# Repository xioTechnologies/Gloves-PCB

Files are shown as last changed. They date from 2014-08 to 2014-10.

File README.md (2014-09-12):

Gloves-PCB
==========

Temporary PCB solution for [the gloves](http://theglovesproject.com/).  Design include five separate PCBs: one main board, two LED boards and two vibration motor boards.  The main board mounts an [x-OSC](http://www.x-io.co.uk/products/x-osc/) an [x-BIMU](http://www.x-io.co.uk/products/x-bimu/) and features an LED bar graph to indicate battery level using the [LM3914](https://www.sparkfun.com/products/12694).  More information available on [blog post](http://theglovesproject.com/breakout-board-for-nime/).

Images
------

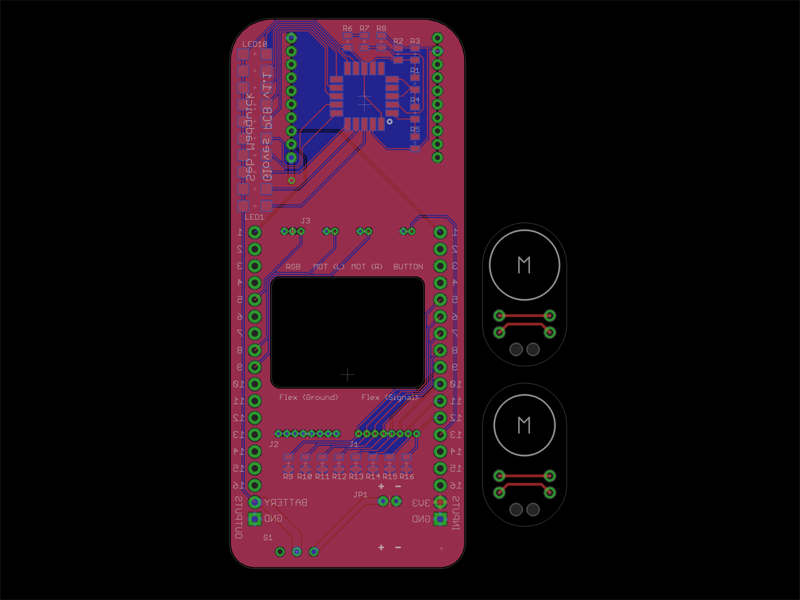
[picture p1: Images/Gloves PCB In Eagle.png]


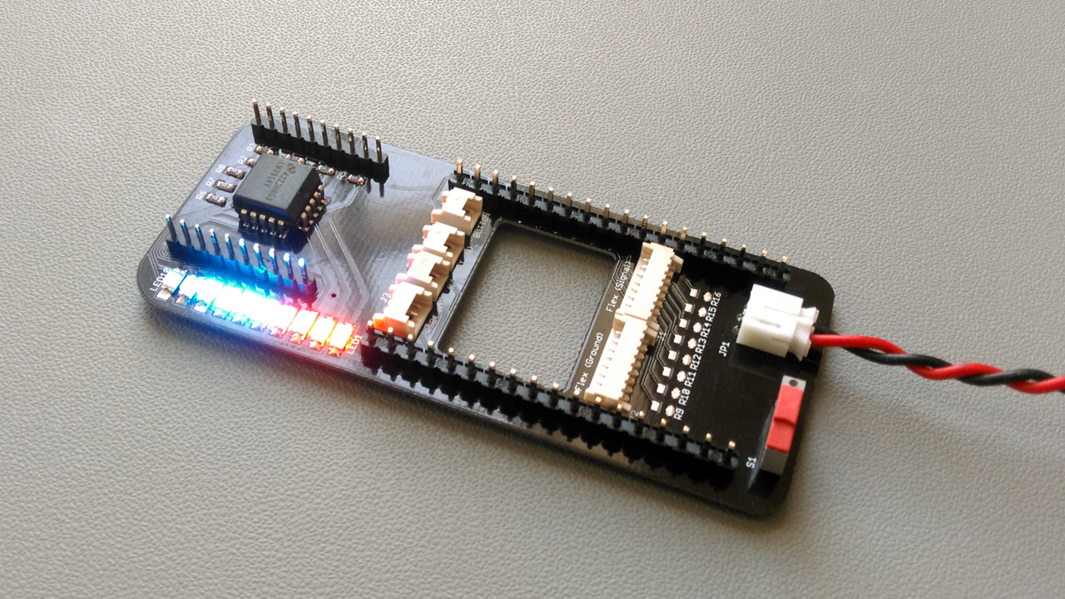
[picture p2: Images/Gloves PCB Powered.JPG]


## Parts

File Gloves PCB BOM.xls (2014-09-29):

ID | Qty | Part | Description
J1, J2 | 2 | Farnell: 973-3094 (http://uk.farnell.com/molex/53048-0810/header-right-angle-8way/dp/9733094?Ntt=973-3094) | 8-way Molex PicoBlade
J3 | 1 | Farnell: 973-2918 (http://uk.farnell.com/molex/53048-0310/connector-header-tht-ra-1-25mm/dp/9732918?Ntt=973-2918) | 3-way Molex PicoBlade
J4, J5, J6 | 3 | Farnell: 101-2259 (http://uk.farnell.com/molex/53048-0210/connector-header-tht-ra-1-25mm/dp/1012259?Ntt=101-2259) | 2-way Molex PicoBlade
JP1 | 1 | RS: S2B-PH-K-S(LF)(SN) (http://uk.rs-online.com/web/p/pcb-headers/5468962/) | JST socket
S1 | 1 | RS: 785-6469 (http://uk.rs-online.com/web/p/products/7856469/) | Slide switch
R1, R4, R5, R6, R7, R8 | 6 | 10k, 603 | Resistor
R2,R3 | 2 | 1k5, 0603 | Resistor
U1 | 1 | RS:534-2983 (http://uk.rs-online.com/web/p/products/5342983/) | LM3914 LED driver
LED1, LED2, LED3, LED4 | 4 | RS: 692-0862 (http://uk.rs-online.com/web/p/products/6920862/) | Orange LED
LED5, LED6, LED7, LED8, LED9, LED10 | 6 | RS: 692-0887 (http://uk.rs-online.com/web/p/products/6920887/) | Blue LED
R9, R10, R11, R12, R13, R14, R15, R16 | 8 | 26k1, 0603 | Resistor
x-BIMU-TH | 2 | Sparkfun: PRT-10112 (https://www.sparkfun.com/products/10112) | 2mm pitch header
x-OSC-TH | 2 | LHCS-18S-R-027-034 (http://www.toby.co.uk/content/catalogue/products.aspx?series=LHCS-xxS-R-027-xxx) | 2.54mm pitch header

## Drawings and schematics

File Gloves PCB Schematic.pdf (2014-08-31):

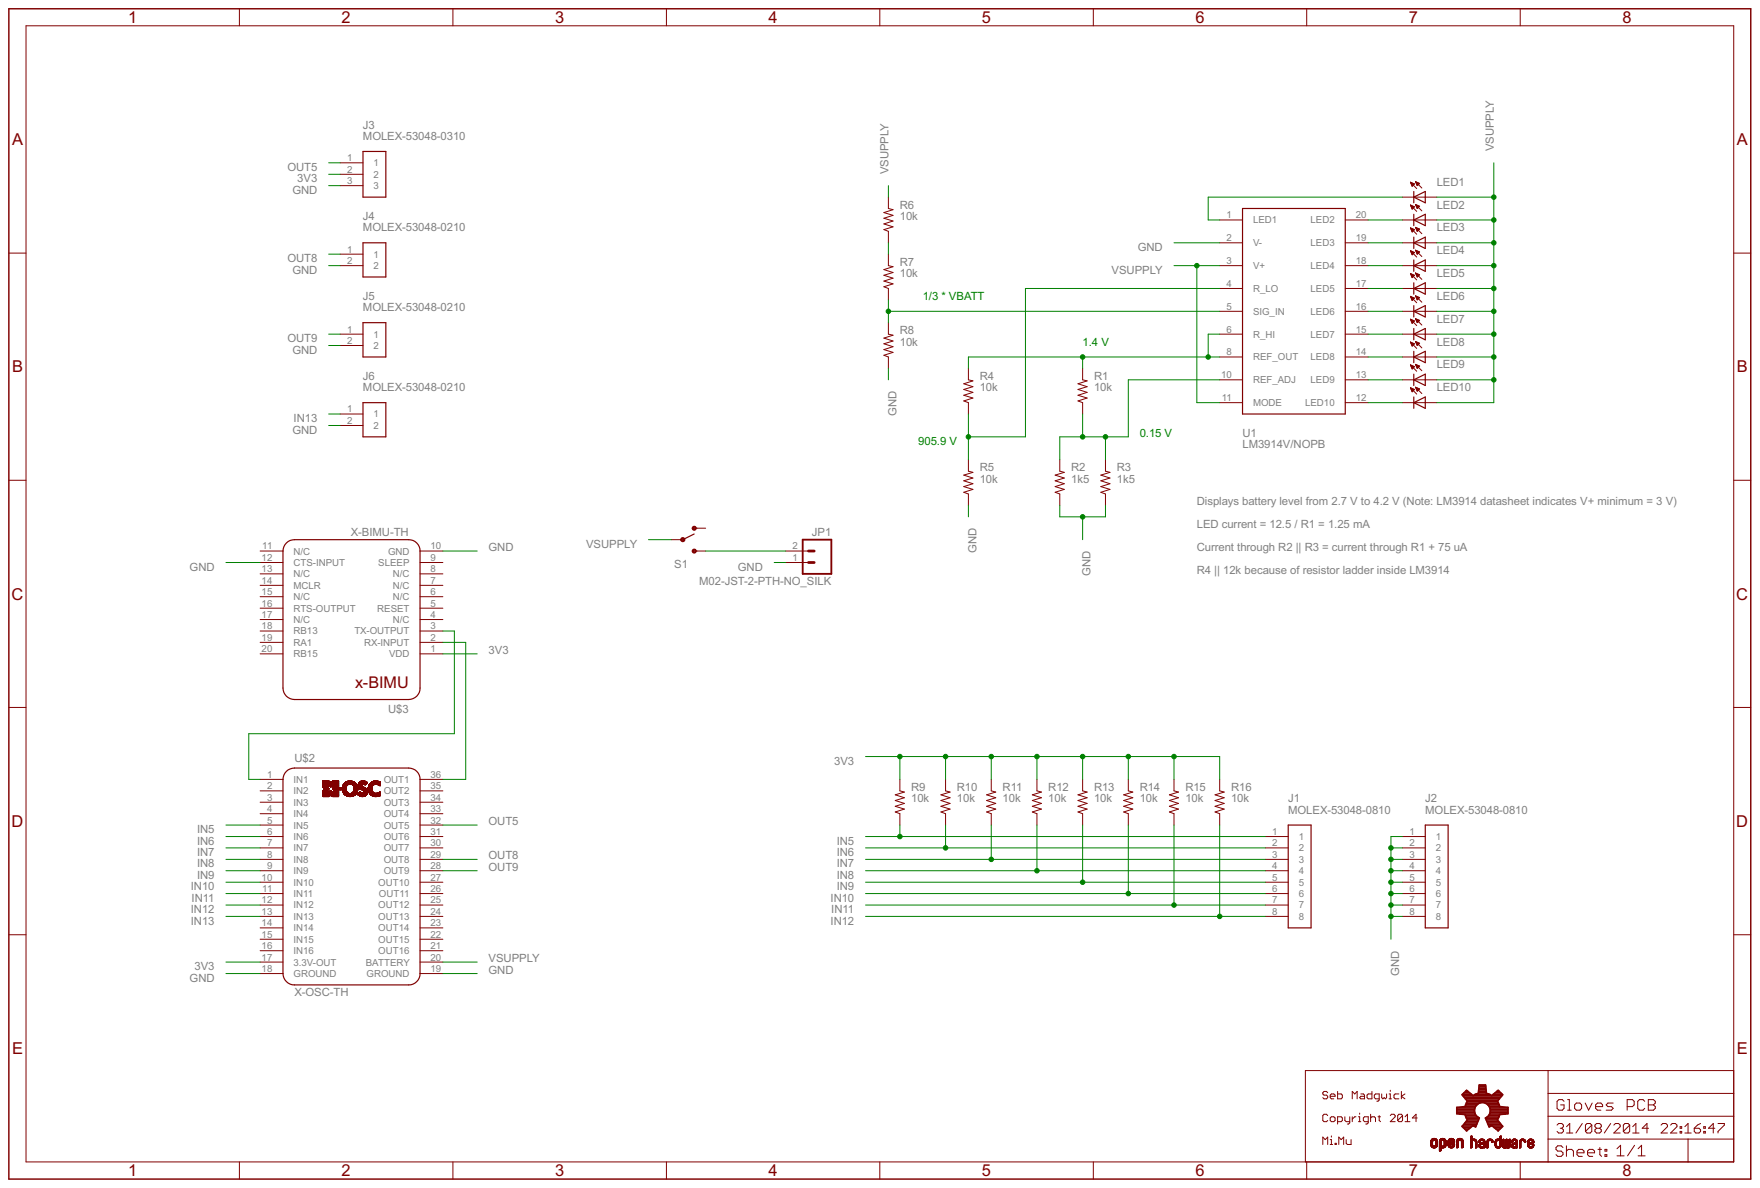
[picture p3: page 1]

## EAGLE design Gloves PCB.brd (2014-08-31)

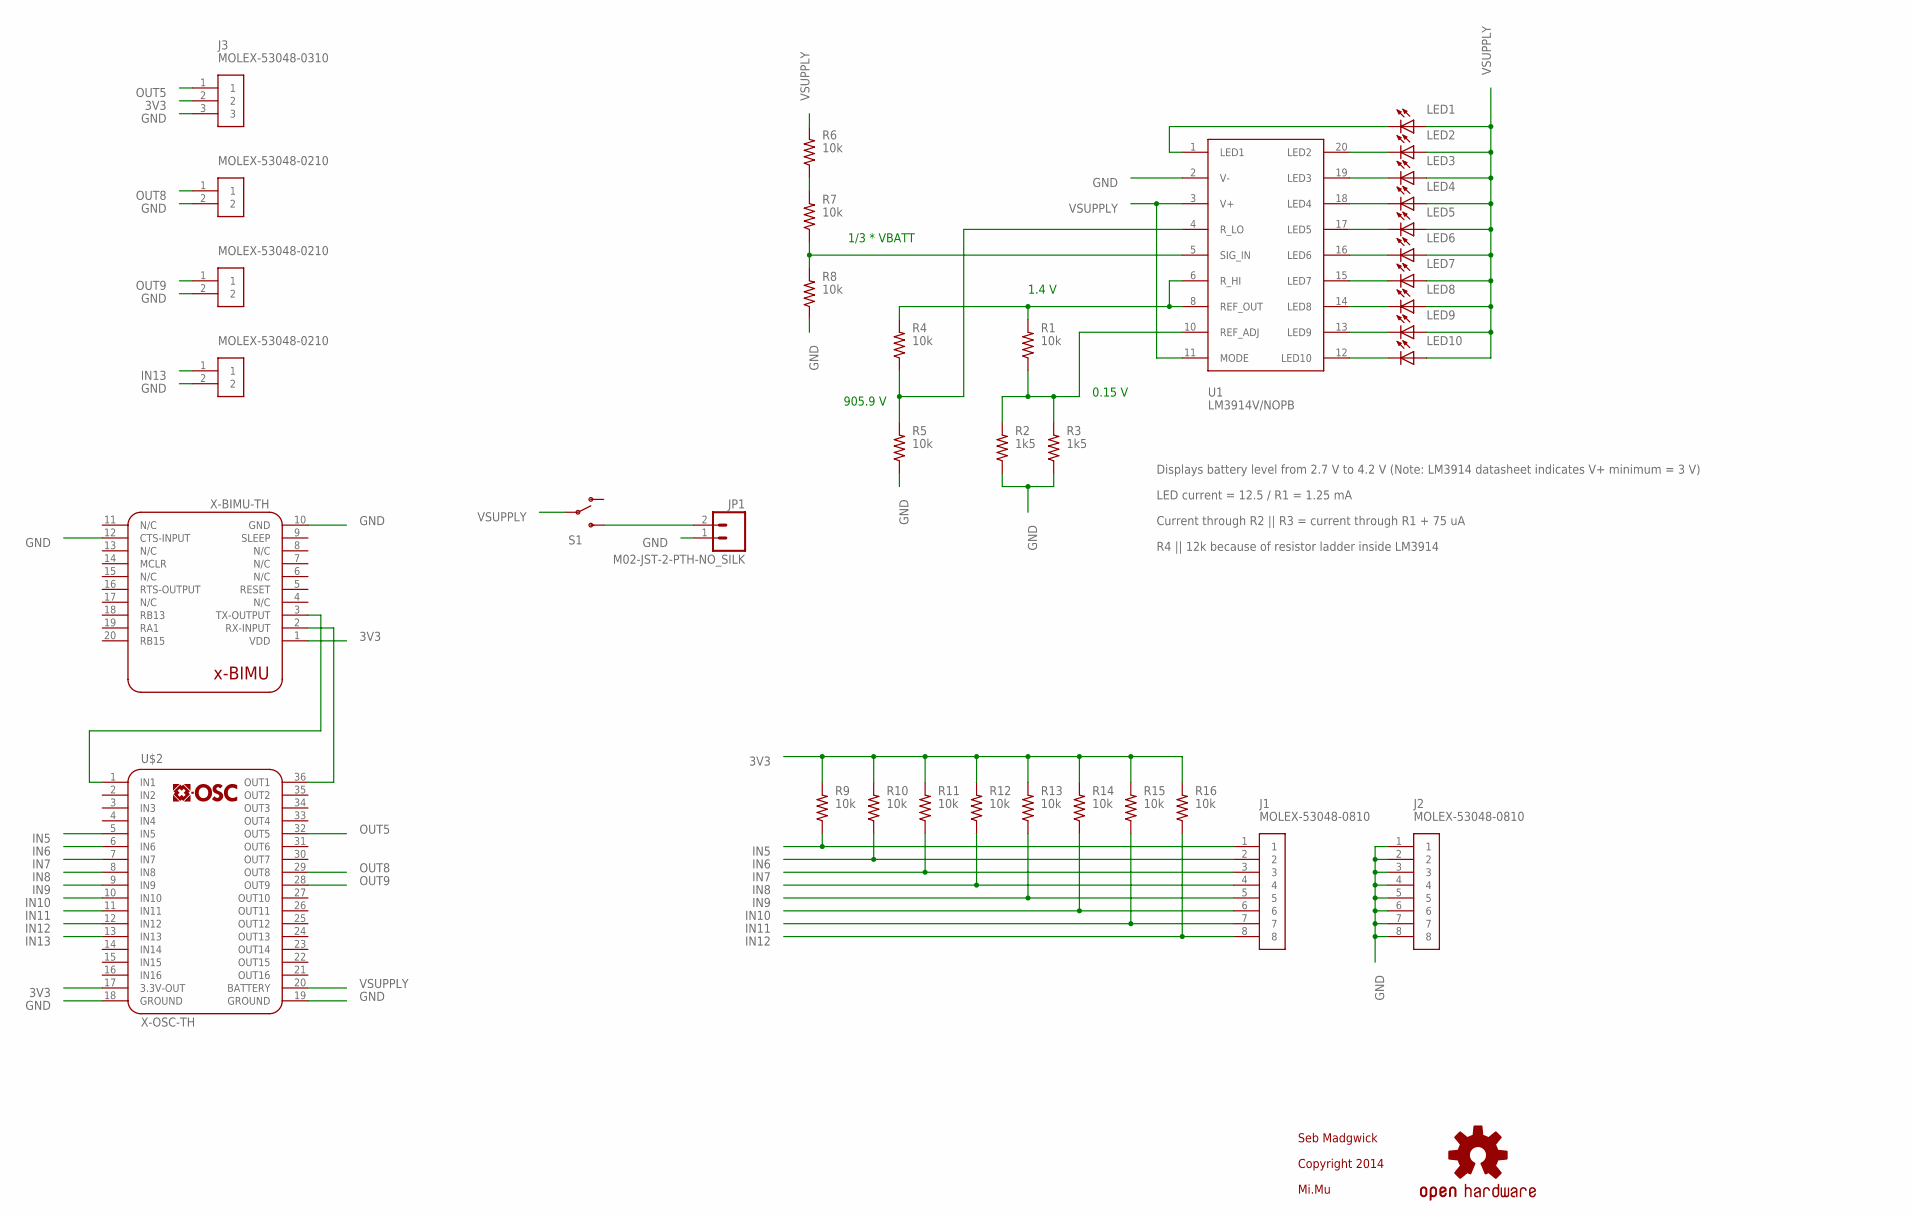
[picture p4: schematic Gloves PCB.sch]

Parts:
J1, J2: MOLEX-53048-0810
J3: MOLEX-53048-0310
J4, J5, J6: MOLEX-53048-0210
JP1: M02-JST-2-PTH-NO_SILK; JST-2-PTH-NS
LED1, LED2, LED3, LED4, LED5, LED6, LED7, LED8, LED9, LED10: LEDCHIPLED_1206; CHIPLED_1206
R1, R4, R5, R6, R7, R8, R9, R10, R11, R12, R13, R14, R15, R16: 10k; 0805
R2, R3: 1k5; 0805
S1: SWITCH-DPST; WURTH-ELEKTRONIK-450301014042
U1: LM3914V/NOPB; PLCC-20
U$1: OSHW-LOGOS; OSHW-LOGO-S
U$2: X-OSC-TH; X-OSC_TH
U$3: X-BIMU-TH; X-BIMU_TH

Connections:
3V3: J3.2, R9.2, R10.2, R11.2, R12.2, R13.2, R14.2, R15.2, R16.2, U$2.17 (3.3V-OUT), U$3.1 (VDD)
GND: J2.1, J2.2, J2.3, J2.4, J2.5, J2.6, J2.7, J2.8, J3.3, J4.2, J5.2, J6.2, JP1.1, R2.1, R3.1, R5.1, R8.1, U1.2 (V-), U$2.18 (GROUND), U$2.19 (GROUND), U$3.10 (GND), U$3.12 (CTS-INPUT)
IN5: J1.1, R9.1, U$2.5 (IN5)
IN6: J1.2, R10.1, U$2.6 (IN6)
IN7: J1.3, R11.1, U$2.7 (IN7)
IN8: J1.4, R12.1, U$2.8 (IN8)
IN9: J1.5, R13.1, U$2.9 (IN9)
IN10: J1.6, R14.1, U$2.10 (IN10)
IN11: J1.7, R15.1, U$2.11 (IN11)
IN12: J1.8, R16.1, U$2.12 (IN12)
IN13: J6.1, U$2.13 (IN13)
unnamed: U$2.1 (IN1), U$3.3 (TX-OUTPUT)
unnamed: R4.1, R5.2, U1.4 (R_LO)
unnamed: JP1.2, S1.3
unnamed: R7.1, R8.2, U1.5 (SIG_IN)
unnamed: R6.1, R7.2
unnamed: R1.1, R2.2, R3.2, U1.10 (REF_ADJ)
unnamed: LED10.C, U1.12 (LED10)
unnamed: LED9.C, U1.13 (LED9)
unnamed: LED8.C, U1.14 (LED8)
unnamed: LED7.C, U1.15 (LED7)
unnamed: LED6.C, U1.16 (LED6)
unnamed: LED5.C, U1.17 (LED5)
unnamed: LED4.C, U1.18 (LED4)
unnamed: LED3.C, U1.19 (LED3)
unnamed: LED2.C, U1.20 (LED2)
unnamed: LED1.C, U1.1 (LED1)
unnamed: U$2.36 (OUT1), U$3.2 (RX-INPUT)
OUT5: J3.1, U$2.32 (OUT5)
OUT8: J4.1, U$2.29 (OUT8)
OUT9: J5.1, U$2.28 (OUT9)
REF_OUT: R1.2, R4.2, U1.6 (R_HI), U1.8 (REF_OUT)
VSUPPLY: LED1.A, LED2.A, LED3.A, LED4.A, LED5.A, LED6.A, LED7.A, LED8.A, LED9.A, LED10.A, R6.2, S1.2, U1.3 (V+), U1.11 (MODE), U$2.20 (BATTERY)

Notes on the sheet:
Seb Madgwick
1.4 V
0.15 V
905.9 V
Displays battery level from 2.7 V to 4.2 V (Note: LM3914 datasheet indicates V+ minimum = 3 V)
1/3 * VBATT
LED current = 12.5 / R1 = 1.25 mA
Current through R2 || R3 = current through R1 + 75 uA
R4 || 12k because of resistor ladder inside LM3914
Copyright 2014
Mi.Mu

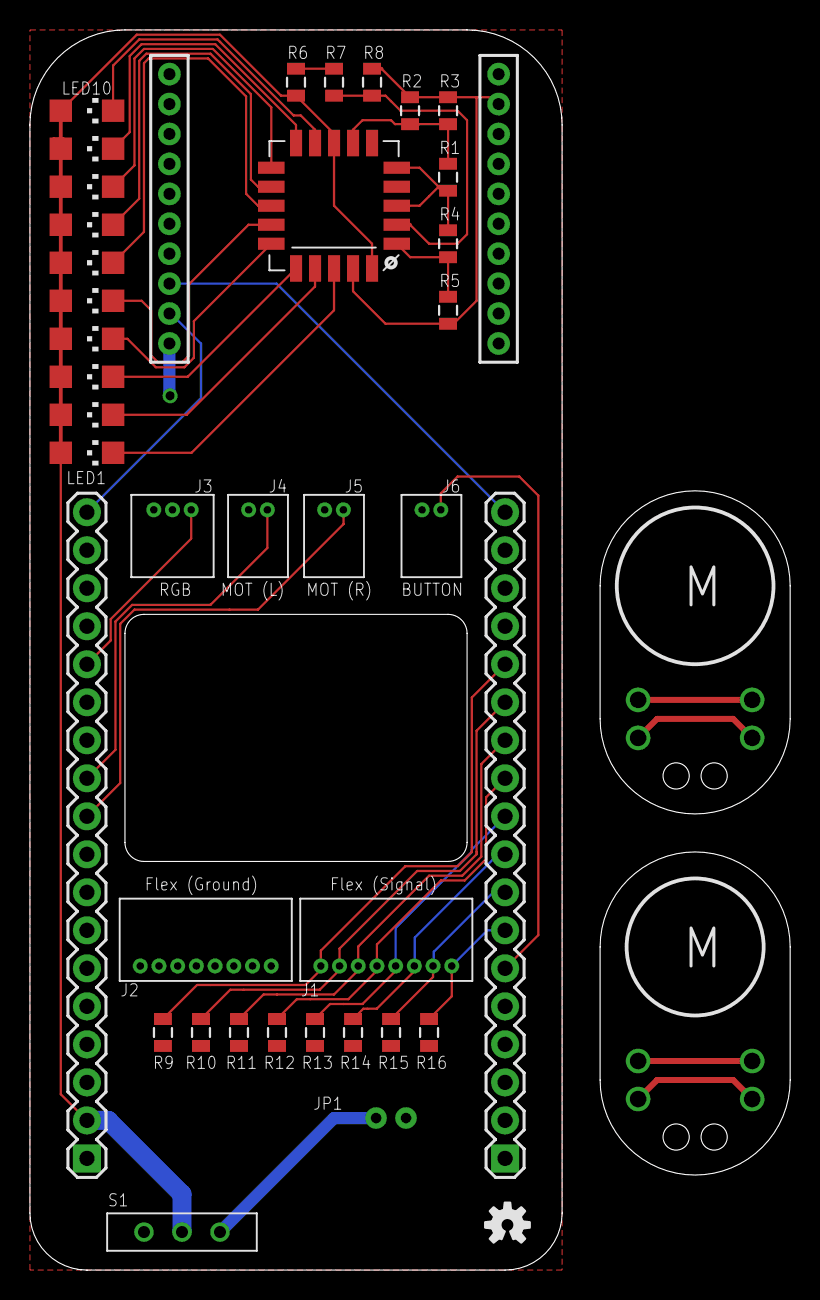
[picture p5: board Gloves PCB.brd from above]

Board: 2 copper layers, 35.6 x 82.9 mm, 38 parts (0 on the bottom side), 33 nets.

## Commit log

2014-04-14 Add project files
    [Gloves PCB.brd, Gloves PCB.sch]
2014-08-31 v1.1 commit
    [Gloves PCB.brd, Gloves PCB.sch]
2014-09-29 Commit BOM
    [Gloves PCB BOM.xls]
2014-10-30 Add motor board files with larger strain relief holes
    [Motor-Boards.brd]

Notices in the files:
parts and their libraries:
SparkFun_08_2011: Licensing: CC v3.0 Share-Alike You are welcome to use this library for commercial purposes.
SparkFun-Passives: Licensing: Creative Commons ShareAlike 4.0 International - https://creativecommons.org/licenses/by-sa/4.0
